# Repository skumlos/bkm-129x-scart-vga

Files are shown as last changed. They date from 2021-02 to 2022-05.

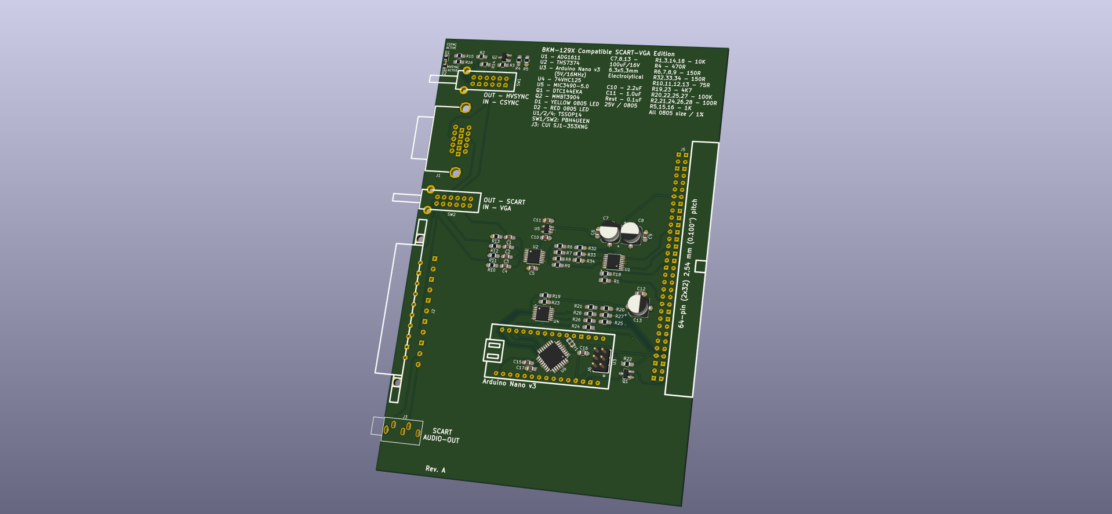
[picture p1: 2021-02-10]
bkm-129x-scart-vga.png

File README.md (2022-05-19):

A SCART/VGA BKM-129X compatible board

Revision F

Should be able to be created at ~$40, with the ADG1611BRUZ being the most expensive component.
Note that the DG1411EEQ is pin-compatible, with a slightly higher Ron.

This requires an Arduino Nano v3 *or* the ATMEGA328PB mounted, which is then loaded with the
latest BKM-129X-MCU code from https://github.com/skumlos/bkm-129x-mcu

The middle 4PDT switch selects SCART or VGA. The top switch selects if the VGA sync signal should combine HV to CSYNC
or just feed CSYNC on. Note that CSYNC should be 75 Ohm level.

You are welcome to clone, produce and sell hardware based on this. Please keep changes and so on open source.

I (finally) upgraded to Kicad 5 during this, so if there are any library issues or whatnot,
let me know, as this was converted from 4.7 to 5.1 automagically.
 
Cool kids give credit where due.

---------

Programming the onboard ATMEGA328PB is a little different than when using a pre-made Arduino board.
The reason for this is that the fuses of the ATMEGA aren't set when the MCU leaves the factory.
Thus to program it, you will need ATMEGA328PB support in the Arduino IDE. The easiest way is to
install the MiniCore board support package (through the Boards Manager), for installation
check the "How to install" at https://github.com/MCUdude/MiniCore.
When MiniCore is available,  select the ATMEGA328 under MiniCore in the board menu, then select
"External 16 MHz" in Clock, disable BOD, select ATMEGA328PB in Variant, select No bootloader.
Then press "Burn bootloader" (assuming your programmer and so on is already setup). This will
program the fuses. Last, upload the sketch by pressing "Upload using programmer". If you don't
do this, nothing will work, because the MCU won't know how to use the external clock and so on.

---------

Should be compatible with basically all monitors that accept the original BKM-129X

Check the MCU code for verified compatibility.

---------

Board revision history:

F: Add option for LD1117 LDO, update to Kicad 5 footprints, minor cosmetical changes

E: Change backplane connector pads to larger ones. Includes silkscreen fix from user 'bodgit', thanks!

D1: Connect VGA pin 5 to GND, fix MIC3490-3.3 -> MIC3490-5.0

D: Remove VGA pin 9 connectivity to GND and leave unconnected.

C: Fixed THS7374 filter bypass, moved sync switch to front.

B: Fixed audio routing

A: Initial version

---------

Copyright © 2022 Martin Hejnfelt <martin@hejnfelt.com>
This work is free. You can redistribute it and/or modify it under the
terms of the Do What The Fuck You Want To Public License, Version 2,
as published by Sam Hocevar. See the LICENSE file for more details.

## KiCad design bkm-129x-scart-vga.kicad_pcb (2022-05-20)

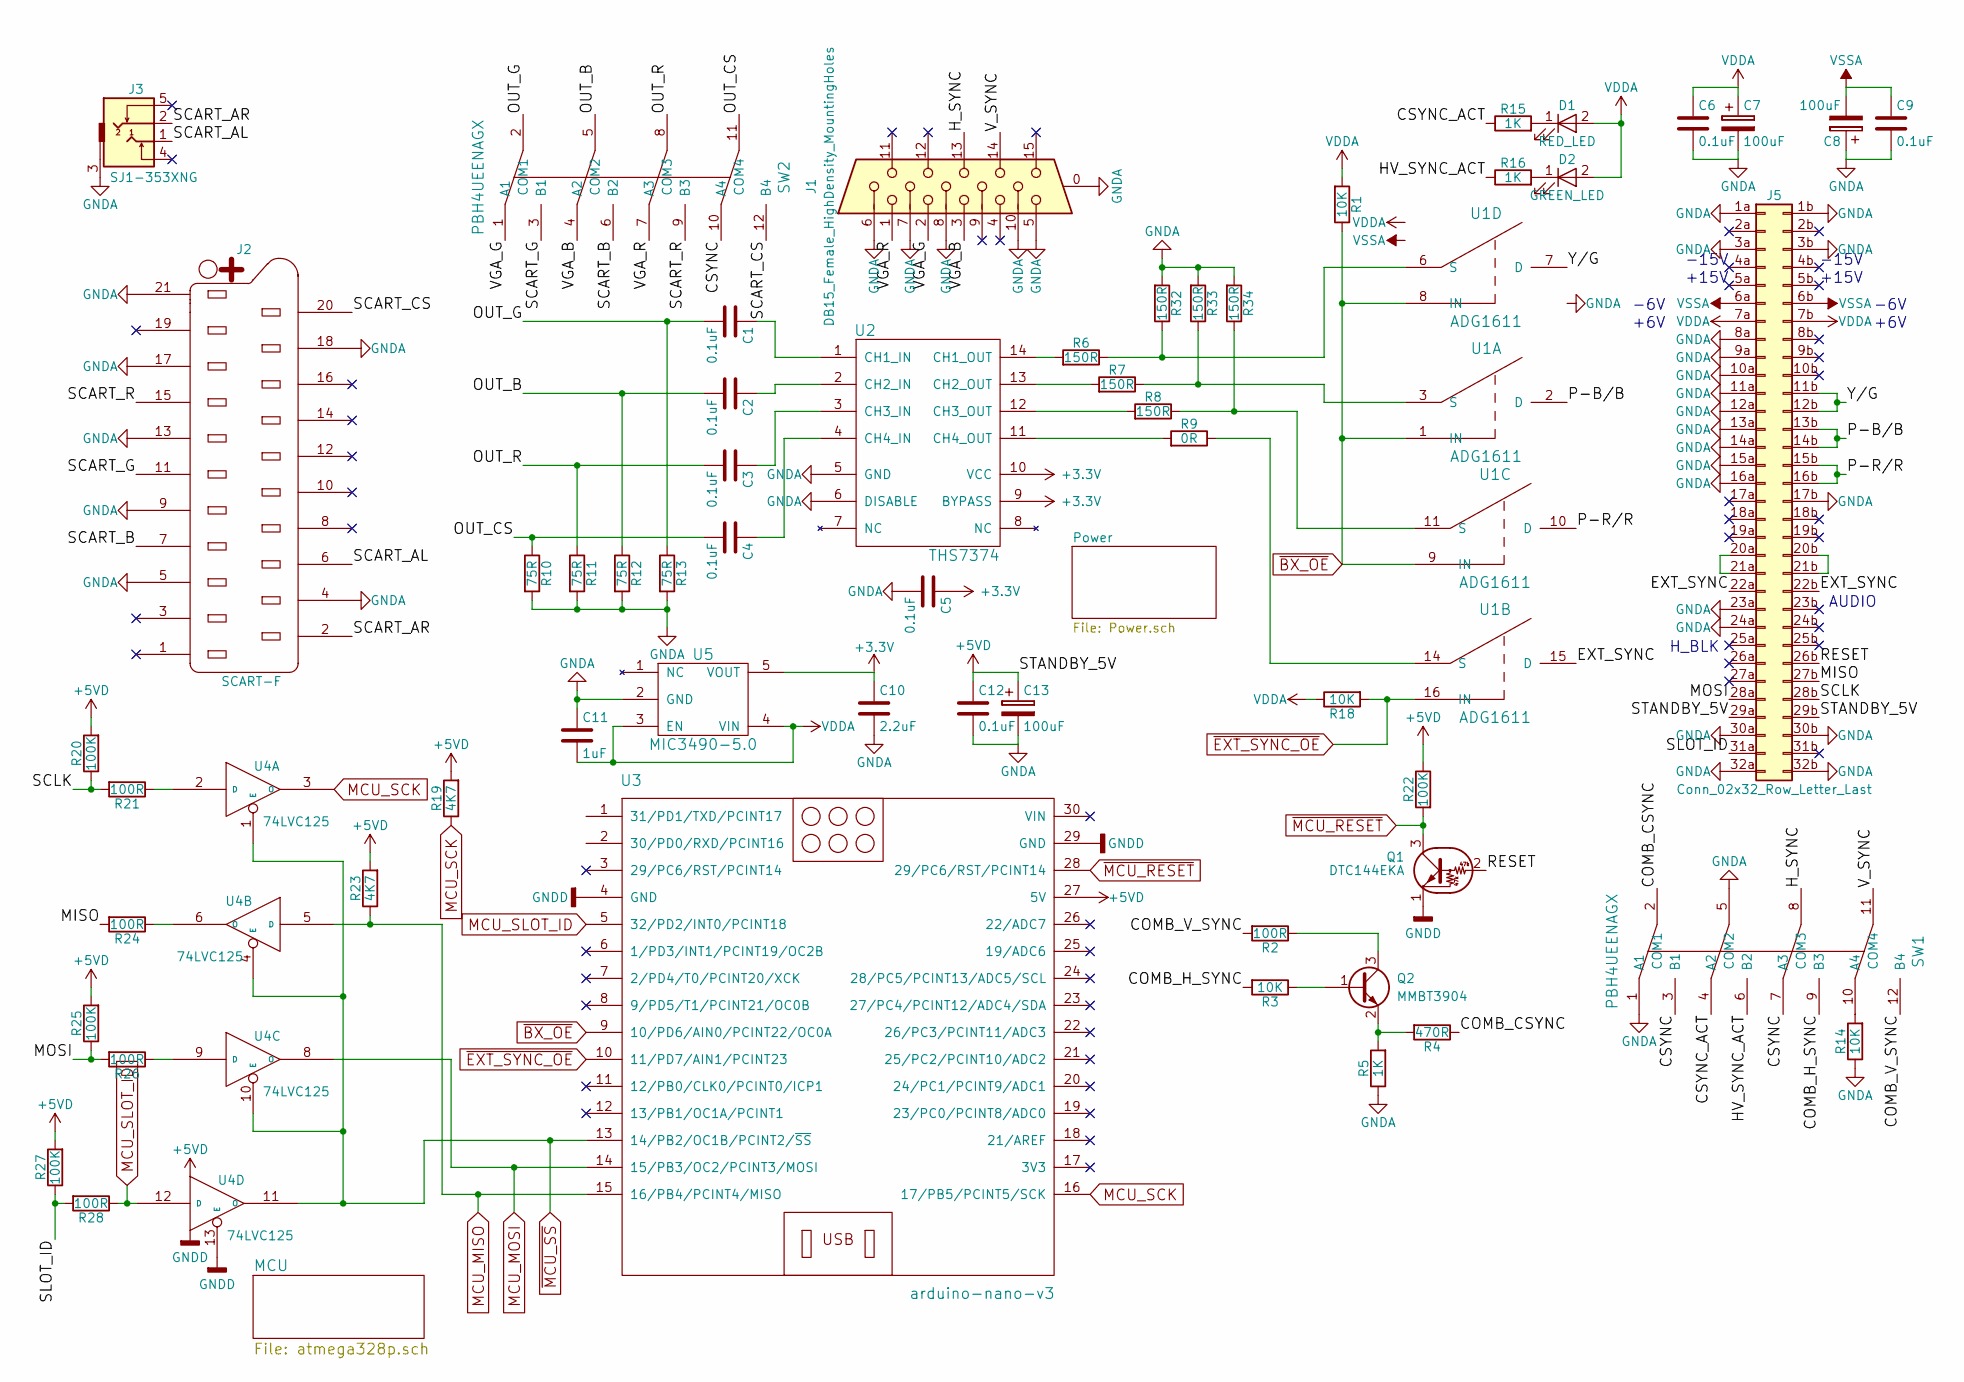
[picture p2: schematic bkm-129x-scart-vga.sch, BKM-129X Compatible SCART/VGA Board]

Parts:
C1, C2, C3, C4, C5, C6, C9, C12: 0.1uF; C_0805_2012Metric_Pad1.18x1.45mm_HandSolder
C7, C8, C13: 100uF; CP_Elec_6.3x5.3
C10: 2.2uF; C_0805_2012Metric_Pad1.18x1.45mm_HandSolder
C11: 1uF; C_0805_2012Metric_Pad1.18x1.45mm_HandSolder
D1: RED_LED; D_0805_2012Metric_Pad1.15x1.40mm_HandSolder
D2: GREEN_LED; D_0805_2012Metric_Pad1.15x1.40mm_HandSolder
J1: DB15_Female_HighDensity_MountingHoles; HD15-VGA
J2: SCART-F; NINIGI-SCART-RA
J3: SJ1-353XNG
J5: Conn_02x32_Row_Letter_Last; STANDARD-PIN-64P-RA
Q1: DTC144EKA; SC-59_Handsoldering
Q2: MMBT3904; SOT-23_Handsoldering
R1, R3, R14, R18: 10K; R_0805_2012Metric_Pad1.20x1.40mm_HandSolder
R2, R21, R24, R26, R28: 100R; R_0805_2012Metric_Pad1.20x1.40mm_HandSolder
R4: 470R; R_0805_2012Metric_Pad1.20x1.40mm_HandSolder
R5, R15, R16: 1K; R_0805_2012Metric_Pad1.20x1.40mm_HandSolder
R6, R7, R8, R32, R33, R34: 150R; R_0805_2012Metric_Pad1.20x1.40mm_HandSolder
R9: 0R; R_0805_2012Metric_Pad1.20x1.40mm_HandSolder
R10, R11, R12, R13: 75R; R_0805_2012Metric_Pad1.20x1.40mm_HandSolder
R19, R23: 4K7; R_0805_2012Metric_Pad1.20x1.40mm_HandSolder
R20, R22, R25, R27: 100K; R_0805_2012Metric_Pad1.20x1.40mm_HandSolder
SW1, SW2: PBH4UEENAGX; PBH4UEE
U1: ADG1611; TSSOP-16_4.4x5mm_P0.65mm
U2: THS7374; TSSOP-14_4.4x5mm_P0.65mm
U3: arduino-nano-v3
U4: 74LVC125; TSSOP-14_4.4x5mm_P0.65mm
U5: MIC3490-5.0; SOT-23-5_HandSoldering

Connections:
+3V3: C5.1, C10.1, U2.9 (BYPASS), U2.10 (VCC), U5.5 (VOUT); also elsewhere on the board
+5VD: C12.1, C13.1, J5.29a, J5.29b, R19.2, R20.2, R22.1, R23.2, R25.2, R27.2, U3.27 (5V), U4.14 (VCC); also elsewhere on the board
/COMB_CSYNC: R4.1, SW1.2 (COM1)
/COMB_H_SYNC: R3.2, SW1.9 (B3)
/COMB_V_SYNC: R2.2, SW1.12 (B4)
/CSYNC: SW1.3 (B1), SW1.7 (A3), SW2.10 (A4)
/CSYNC_ACT: R15.1, SW1.4 (A2)
/EXT_SYNC: J5.22a, J5.22b, U1.15 (D)
/HV_SYNC_ACT: R16.1, SW1.6 (B2)
/H_SYNC: J1.13, SW1.8 (COM3)
/MISO: J5.27b, R24.2
/MOSI: J5.28a, R25.1, R26.2
/OUT_B: C2.2, R12.1, SW2.5 (COM2)
/OUT_CS: C4.2, R10.1, SW2.11 (COM4)
/OUT_G: C1.2, R13.1, SW2.2 (COM1)
/OUT_R: C3.2, R11.1, SW2.8 (COM3)
/P-B/B: J5.13b, J5.14b, U1.2 (D)
/P-R/R: J5.15b, J5.16b, U1.10 (D)
/RESET: J5.26b, Q1.2 (B)
/SCART_AL: J2.6, J3.1
/SCART_AR: J2.2, J3.2
/SCART_B: J2.7, SW2.6 (B2)
/SCART_CS: J2.20, SW2.12 (B4)
/SCART_G: J2.11, SW2.3 (B1)
/SCART_R: J2.15, SW2.9 (B3)
/SCLK: J5.28b, R20.1, R21.2
/SLOT_ID: J5.31a, R27.1, R28.2
/VGA_B: J1.3, SW2.4 (A2)
/VGA_G: J1.2, SW2.1 (A1)
/VGA_R: J1.1, SW2.7 (A3)
/V_SYNC: J1.14, SW1.11 (COM4)
/Y/G: J5.11b, J5.12b, U1.7 (D)
MCU_MISO: R23.1, U3.15 (16/PB4/PCINT4/MISO), U4.5 (D); also elsewhere on the board
MCU_MOSI: U3.14 (15/PB3/OC2/PCINT3/MOSI), U4.8 (O); also elsewhere on the board
MCU_SCK: R19.1, U3.16 (17/PB5/PCINT5/SCK), U4.3 (O); also elsewhere on the board
MCU_SLOT_ID: R28.1, U3.5 (32/PD2/INT0/PCINT18), U4.12 (D); also elsewhere on the board
unnamed: C1.1, U2.1 (CH1_IN)
unnamed: C2.1, U2.2 (CH2_IN)
unnamed: C3.1, U2.3 (CH3_IN)
unnamed: C4.1, U2.4 (CH4_IN)
unnamed: D1.1 (K), R15.2
unnamed: D2.1 (K), R16.2
unnamed: J5.20a, J5.21a
unnamed: J5.20b, J5.21b
unnamed: Q2.1 (B), R3.1
unnamed: Q2.2 (E), R4.2, R5.2
unnamed: Q2.3 (C), R2.1
unnamed: R6.2, U2.14 (CH1_OUT)
unnamed: R7.2, U2.13 (CH2_OUT)
unnamed: R8.2, U2.12 (CH3_OUT)
unnamed: R9.1, U1.14 (S)
unnamed: R9.2, U2.11 (CH4_OUT)
unnamed: R14.2, SW1.10 (A4)
unnamed: R21.1, U4.2 (D)
unnamed: R24.1, U4.6 (O)
unnamed: R26.1, U4.9 (D)
unnamed: R6.1, R32.1, U1.6 (S)
unnamed: R7.1, R33.1, U1.3 (S)
unnamed: R8.1, R34.1, U1.11 (S)
VDD: C6.1, C7.1, C11.2, D1.2 (A), D2.2 (A), J5.7a, J5.7b, R1.2, R18.1, U1.13 (VDD), U5.3 (EN), U5.4 (VIN); also elsewhere on the board
VSS: C8.2, C9.1, J5.6a, J5.6b, U1.4 (VSS)
~BX_OE: R1.1, U1.1 (IN), U1.8 (IN), U1.9 (IN), U3.9 (10/PD6/AIN0/PCINT22/OC0A); also elsewhere on the board
~EXT_SYNC_OE: R18.2, U1.16 (IN), U3.10 (11/PD7/AIN1/PCINT23); also elsewhere on the board
~MCU_RESET: Q1.3 (C), R22.2, U3.28 (29/PC6/RST/PCINT14); also elsewhere on the board
~MCU_SS: U3.13 (14/PB2/OC1B/PCINT2/~SS), U4.1 (E), U4.4 (E), U4.10 (E), U4.11 (O); also elsewhere on the board

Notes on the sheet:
-15V
+15V
-6V
+6V
AUDIO
H_BLK

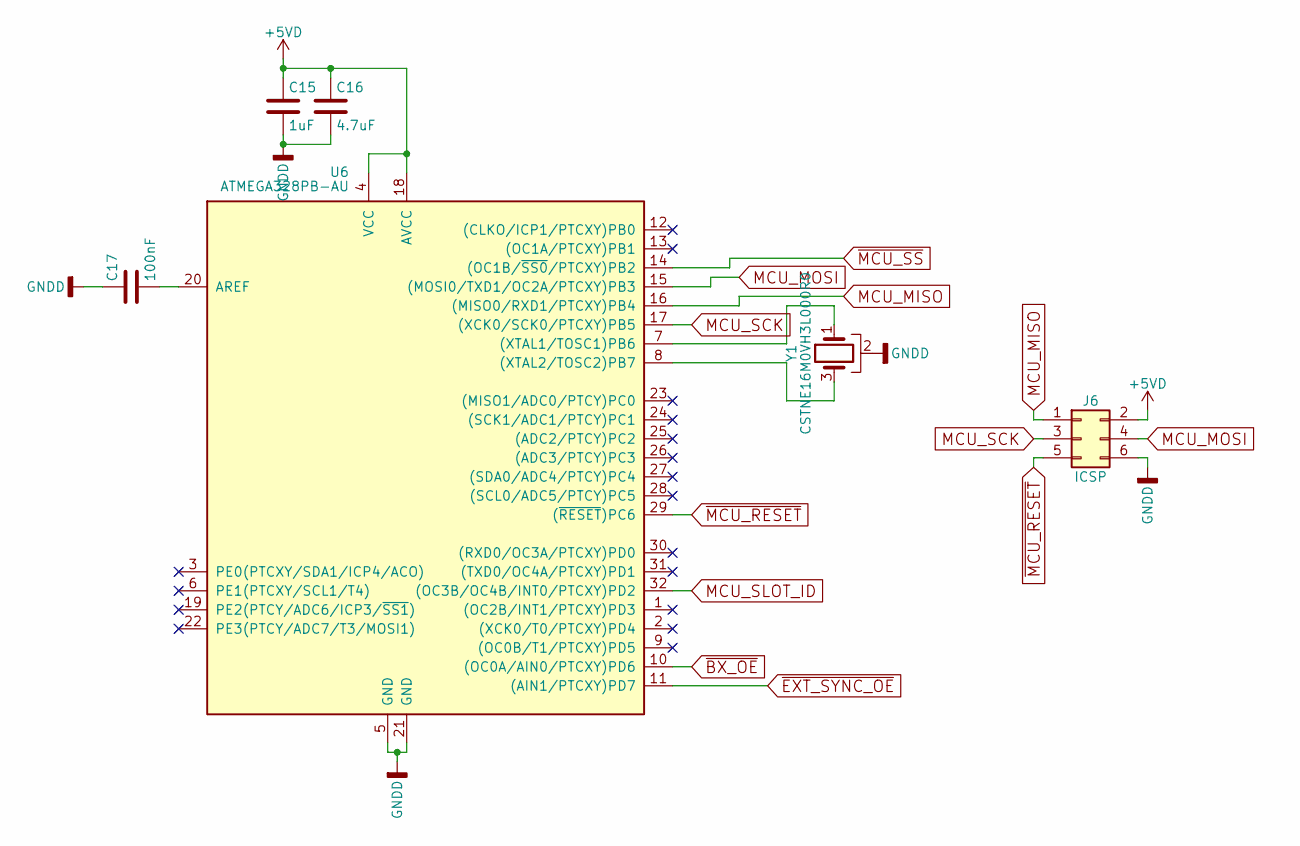
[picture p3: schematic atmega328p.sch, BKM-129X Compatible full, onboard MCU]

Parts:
C15: 1uF; C_0805_2012Metric_Pad1.18x1.45mm_HandSolder
C16: 4.7uF; C_0805_2012Metric_Pad1.18x1.45mm_HandSolder
C17: 100nF; C_0805_2012Metric_Pad1.18x1.45mm_HandSolder
J6: ICSP; Pin_Header_Straight_2x03_Pitch2.54mm
U6: ATMEGA328PB-AU; TQFP-32_7x7mm_P0.8mm
Y1: CSTNE16M0VH3L000R0; Resonator_SMD_muRata_CSTxExxV-3Pin_3.0x1.1mm

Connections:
+5VD: C15.1, C16.1, J6.2, U6.4 (VCC), U6.18 (AVCC); also elsewhere on the board
MCU_MISO: J6.1, U6.16 ((MISO0/RXD1/PTCXY)PB4); also elsewhere on the board
MCU_MOSI: J6.4, U6.15 ((MOSI0/TXD1/OC2A/PTCXY)PB3); also elsewhere on the board
MCU_SCK: J6.3, U6.17 ((XCK0/SCK0/PTCXY)PB5); also elsewhere on the board
MCU_SLOT_ID: U6.32 ((OC3B/OC4B/INT0/PTCXY)PD2); also elsewhere on the board
unnamed: C17.2, U6.20 (AREF)
unnamed: U6.7 ((XTAL1/TOSC1)PB6), Y1.1
unnamed: U6.8 ((XTAL2/TOSC2)PB7), Y1.3
~BX_OE: U6.10 ((OC0A/AIN0/PTCXY)PD6); also elsewhere on the board
~EXT_SYNC_OE: U6.11 ((AIN1/PTCXY)PD7); also elsewhere on the board
~MCU_RESET: J6.5, U6.29 ((~RESET~)PC6); also elsewhere on the board
~MCU_SS: U6.14 ((OC1B/~SS0~/PTCXY)PB2); also elsewhere on the board

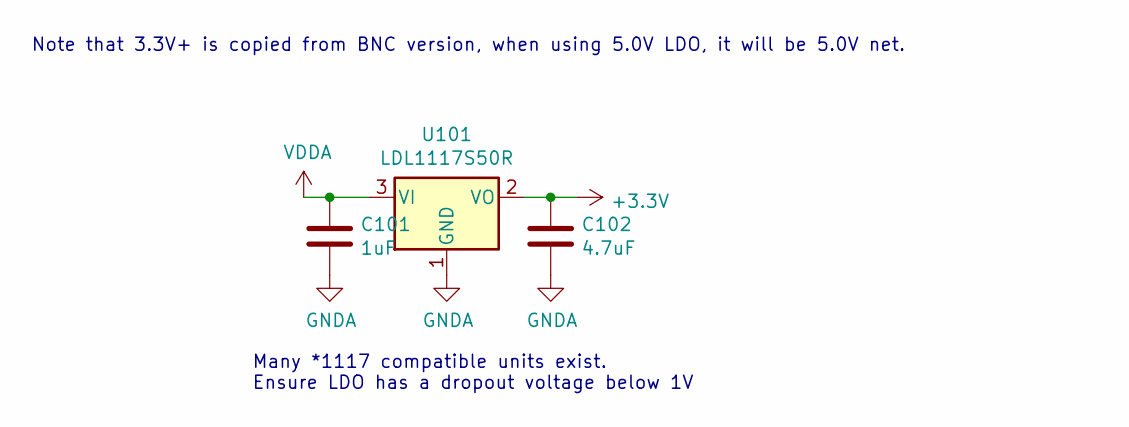
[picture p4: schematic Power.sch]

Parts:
C101: 1uF; C_0805_2012Metric_Pad1.18x1.45mm_HandSolder
C102: 4.7uF; C_0805_2012Metric_Pad1.18x1.45mm_HandSolder
U101: LDL1117S50R; SOT-223-3_TabPin2

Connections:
+3V3: C102.1, U101.2 (VO); also elsewhere on the board
VDD: C101.1, U101.3 (VI); also elsewhere on the board

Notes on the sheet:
Note that 3.3V+ is copied from BNC version, when using 5.0V LDO, it will be 5.0V net.
Many *1117 compatible units exist. Ensure LDO has a dropout voltage below 1V

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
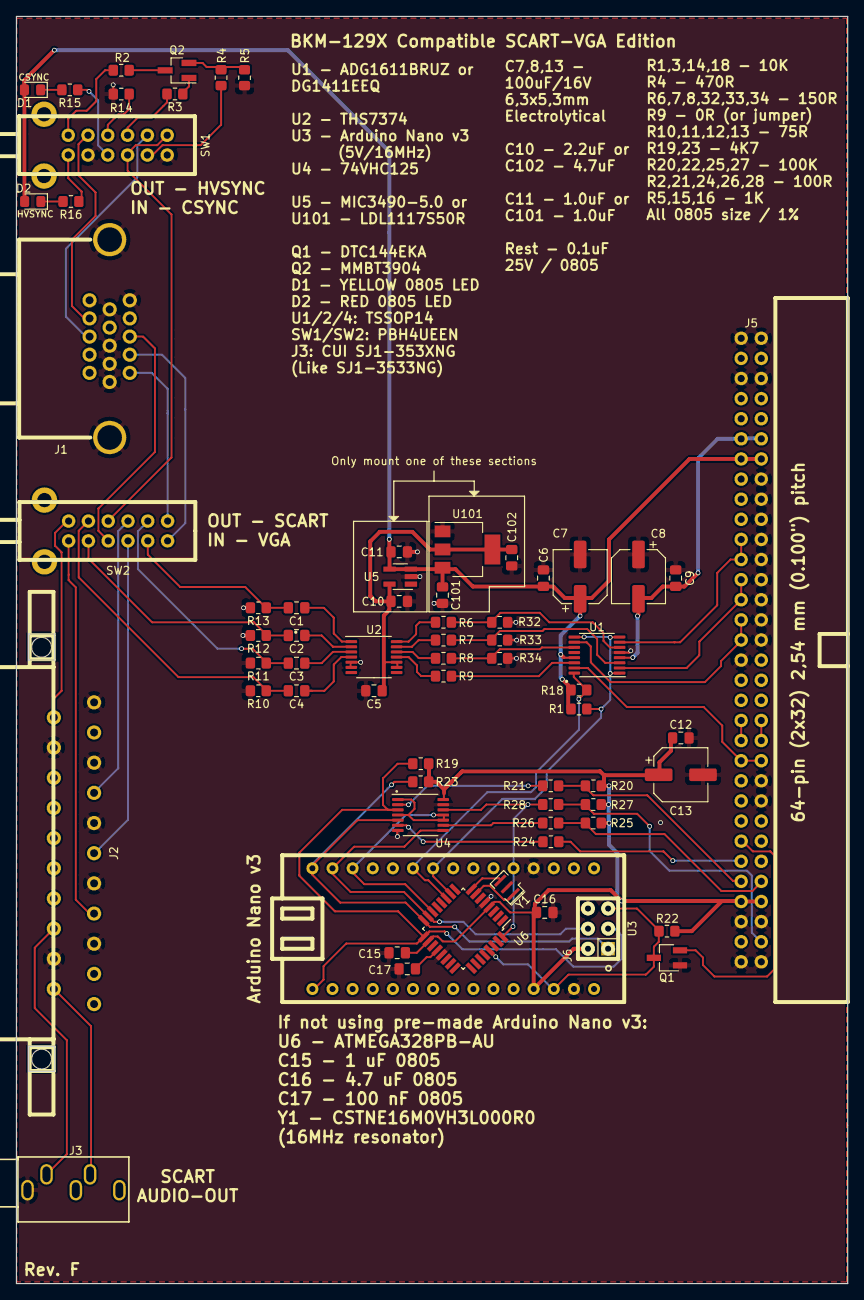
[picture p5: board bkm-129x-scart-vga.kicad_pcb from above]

Board: 2 copper layers, 105.0 x 160.0 mm, 67 parts (0 on the bottom side), 69 nets.

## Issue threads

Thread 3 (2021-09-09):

3D printed bracket

bodgit, 2021-09-09:
Did you ever create a 3D printed bracket for this version of the BKM board? I can see 4x/8x BNC and the simple SCART versions on Thingiverse but not this one.

skumlos, 2021-09-09:
There is one on Thingiverse, I have not tested it and not by me: https://www.thingiverse.com/herzmx/designs

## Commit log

2021-04-04 Rev. C. Move to Kicad 5
    [bkm-129x-scart-vga.kicad_pcb, bkm-129x-scart-vga.sch]
2021-04-04 Add plot
    [bkm-129x-scart-vga-B_Cu.gbr, bkm-129x-scart-vga-B_Mask.gbr, bkm-129x-scart-vga-B_SilkS.gbr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]
2021-05-09 Rev. D
    [bkm-129x-scart-vga-B_Cu.gbr, bkm-129x-scart-vga-B_Mask.gbr, bkm-129x-scart-vga-B_SilkS.gbr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]
2021-08-02 Correct U5 part number
    Schematic says it's the -3.3 version.
    [bkm-129x-scart-vga.kicad_pcb]
2021-08-09 Rev. D1
    [bkm-129x-scart-vga-B_Cu.gbr, bkm-129x-scart-vga-B_Mask.gbr, bkm-129x-scart-vga-B_SilkS.gbr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]
2021-09-08 Fix R9 value on silkscreen
    Schematic says R9 is 0Ω, silkscreen says it's 150Ω. Also condense the
    remaining 150Ω resistors into one line.
    [bkm-129x-scart-vga.kicad_pcb]
2021-09-08 Rev. E
    [bkm-129x-scart-vga-B_Cu.gbr, bkm-129x-scart-vga-B_Mask.gbr, bkm-129x-scart-vga-B_SilkS.gbr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]
2022-05-19 Update to rev. F
    [atmega328p.sch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]
2022-05-19 Added missing new sheet
    [Power.sch]
2022-05-20 Fixed 1117 PN to LDL1117S50R
    [Power.sch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]
